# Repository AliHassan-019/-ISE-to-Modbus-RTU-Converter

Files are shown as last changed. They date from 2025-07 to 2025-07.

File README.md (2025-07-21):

<h1 align="center">ISE-to-Modbus-RTU-Converter</h1>

<p align="center">
  <b>Precision Analog Front-End & Industrial Modbus RTU Converter</b><br>
  <i>Robust, Isolated, and Noise-Immune Hardware for Scientific & Industrial Sensing</i>
</p>

---

<p align="center">
  
  
  
</p>

---

## 🚀 Overview

The **ISE-to-Modbus-RTU-Converter** is a state-of-the-art embedded hardware platform designed for high-precision analog signal acquisition and robust digital communication in industrial and scientific environments. It features a multi-stage, isolated power supply, a 24-bit high-resolution ADC, and a powerful microcontroller for seamless Modbus RTU communication. This converter is ideal for interfacing with pH (ISE) sensors, gas sensors, biomedical instrumentation, and other applications requiring accurate, low-level signal acquisition and reliable industrial communication.

---

## 🎯 Project Objectives

The primary goal is to deliver a robust, electrically isolated, and noise-immune analog front-end that ensures:
- **Accurate low-level signal acquisition**
- **Reliable, standards-compliant Modbus RTU communication**
- **Electrical safety and EMI immunity**
- **Easy integration with PLCs, SCADA, and industrial controllers**

---

## ⚙️ Features

- **Multi-stage Isolated Power Supply**: +12V input, isolated DC-DC, low-noise LDO for analog and digital domains
- **High-Resolution ADC**: 24-bit, differential input, programmable gain, internal/external reference
- **Industrial Microcontroller**: 32-bit, low-power, with SPI, I2C, UART/RS-485, GPIO
- **Modbus RTU Communication**: Hardware RS-485 transceiver, direction control, robust protocol stack
- **Peripheral Support**: I2C EEPROM, 1-Wire temperature sensor, test points, debug header
- **4-Layer PCB**: Optimized for EMI, thermal, and mechanical performance
- **Comprehensive Firmware**: Real-time data acquisition, Modbus stack, diagnostics

---

## 🏗️ System Architecture

```mermaid
graph TD;
    PWR[+12V Input] --> PROT[Protection: Diode & Fuse]
    PROT --> DCISO[Isolated DC-DC Converter]
    DCISO --> LDO[Low-Noise LDO Regulator]
    LDO --> VANA[+3.3V Analog Supply]
    VANA --> MCU[Microcontroller]
    VANA --> ADC[24-bit ADC]
    ADC -->|SPI| MCU
    MCU -->|UART/RS-485| RS485[RS-485 Transceiver]
    MCU -->|I2C| EEPROM[EEPROM]
    MCU -->|1-Wire| TEMP[DS18B20 Temp Sensor]
    MCU --> GPIO[GPIO/Debug]
```

---

## 🖥️ Schematic

<p align="center">
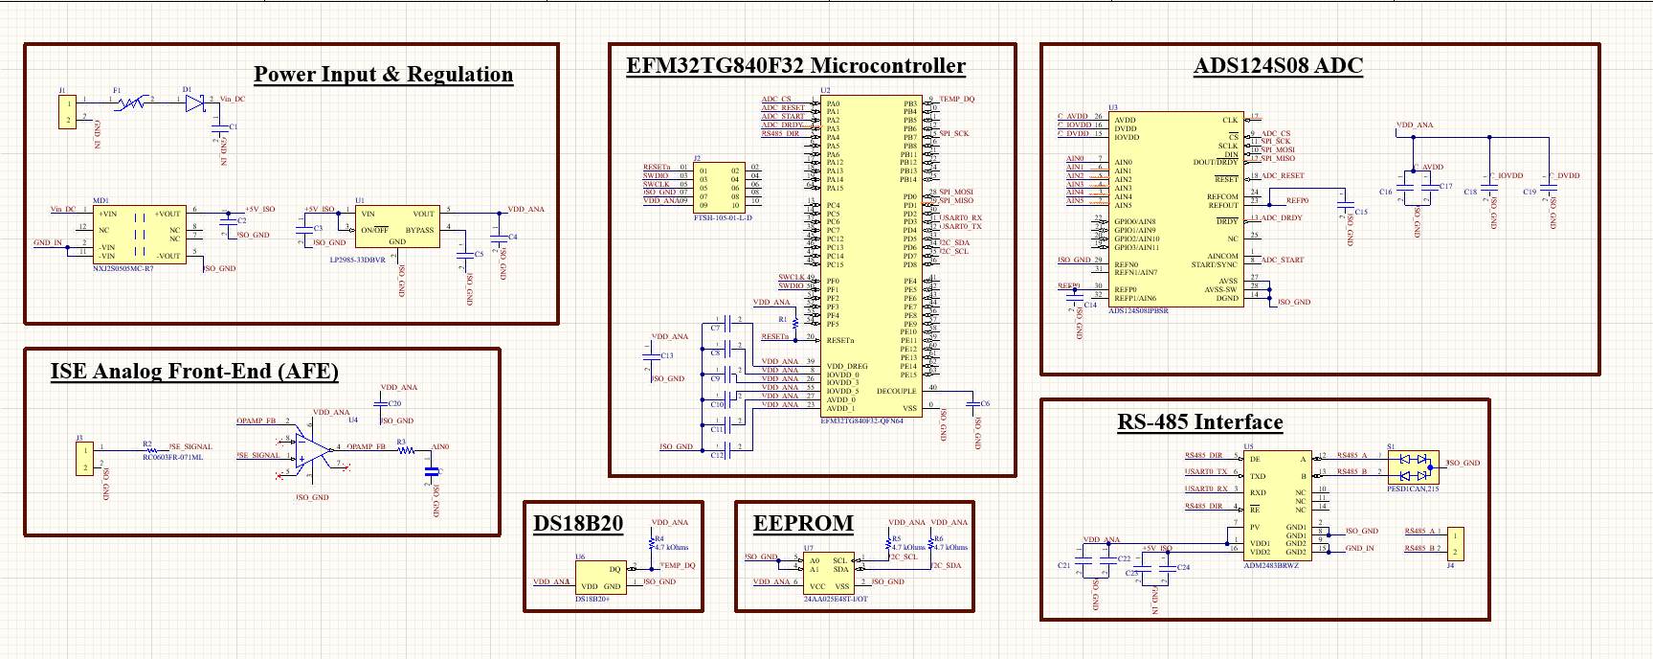
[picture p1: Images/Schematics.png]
Schematic
  
</p>

---

## 📐 Hardware Design

### Power Supply
The power supply accepts a +12V input, protected by a diode and fuse, and feeds an isolated DC-DC converter. The +5V_ISO output is regulated to a low-noise +3.3V analog supply via an LDO. This architecture ensures galvanic isolation and minimal noise for sensitive analog measurements.

### Microcontroller
A low-power, 32-bit MCU (e.g., EFM32TG840F32) manages all digital interfaces, including SPI (for ADC), I2C (for EEPROM), UART/RS-485 (for Modbus), and GPIOs. The MCU is powered from the clean analog supply, maintaining a unified ground reference.

### ADC
The ADS124S08 (or similar) 24-bit ADC interfaces with differential analog sensors. It supports programmable gain, internal/external reference, and advanced filtering for high-accuracy measurements.

### Communication
An RS-485 transceiver with direction control enables robust Modbus RTU communication. I2C EEPROM provides non-volatile storage, and a DS18B20 1-Wire sensor monitors board temperature.

### Layout & Decoupling
All blocks are decoupled with high-frequency capacitors, with careful separation of analog and digital ground planes. EMI filters and ferrite beads are used to suppress noise and ensure signal integrity.

## 🧩 PCB Design & Stack-Up

This project uses a 4-layer PCB for optimal signal integrity and EMI performance:

- **Top Layer:** Components, high-speed and analog routing
- **Inner Layer 1 (GND):** Solid ground plane for shielding and return paths
- **Inner Layer 2 (Power):** Clean analog/digital power rails (+3.3V, +5V_ISO)
- **Bottom Layer:** Passives, low-priority signals, mechanical support

**Board Size:** 200mm × 16mm (optimized for DIN-rail or slim enclosures)

---

## 🖼️ PCB Visuals

### Top 3D View
<p align="center">
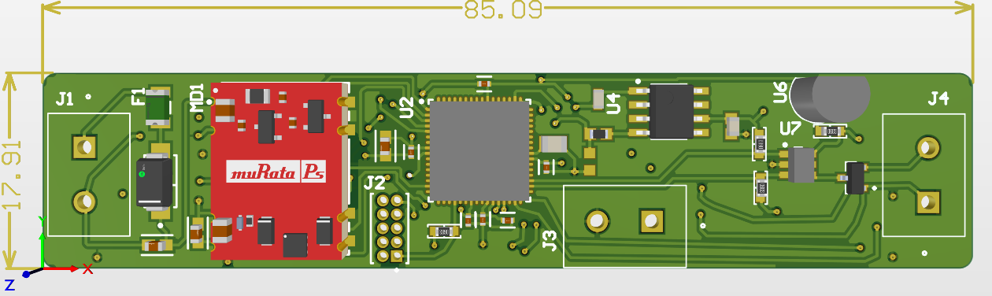
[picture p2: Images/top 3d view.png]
Top 3D View
  
</p>
This view shows the populated top side, including the MCU, ADC, protection, and filtering components. Placement is optimized for signal flow and manufacturability.

### Bottom 3D View
<p align="center">
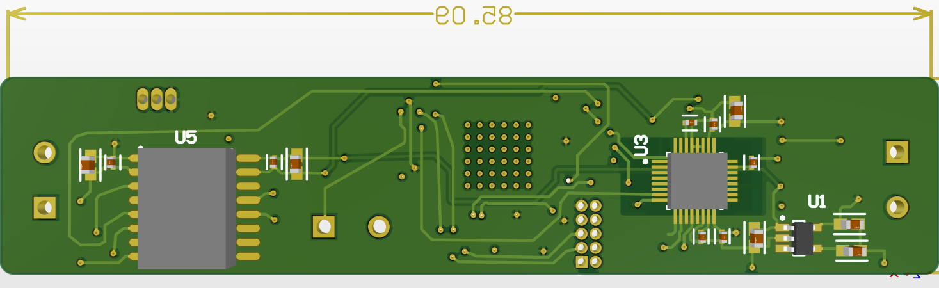
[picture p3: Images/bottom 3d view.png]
Bottom 3D View
  
</p>
The bottom side contains SMD passives, vias, and traces, kept clean for soldering and signal routing.

### Top Layer
<p align="center">
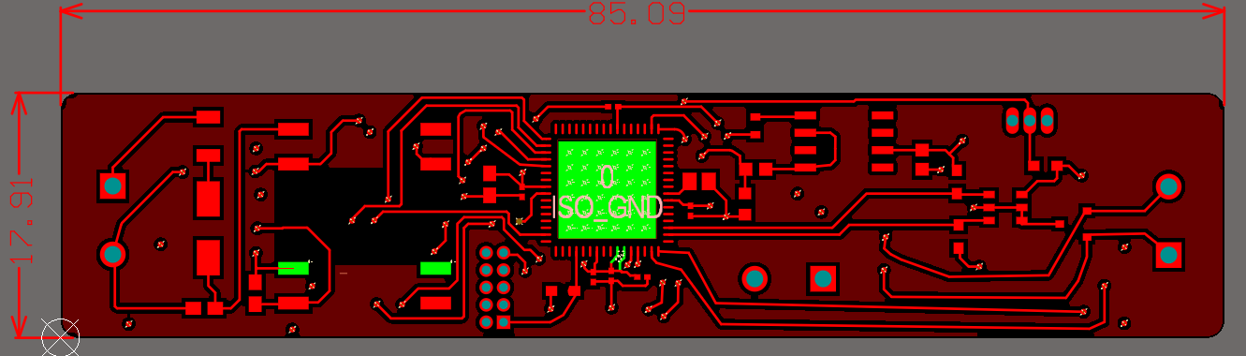
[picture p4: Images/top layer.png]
Top Layer
  
</p>
Main analog and digital signal routing, with careful clearance between domains.

### Inner Ground Layer
<p align="center">
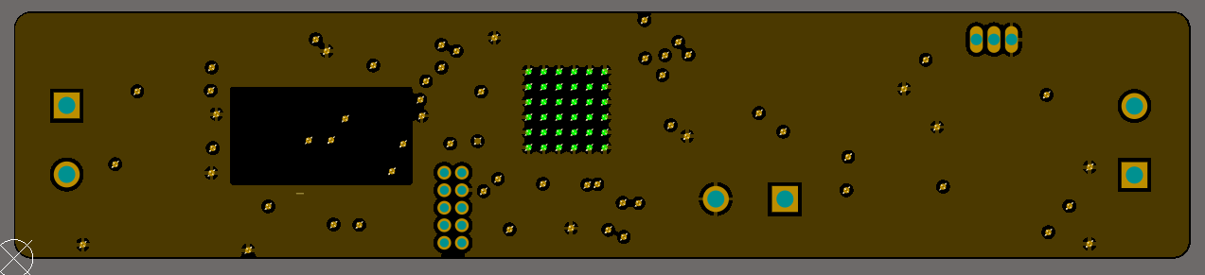
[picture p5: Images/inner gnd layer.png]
Inner GND Layer
  
</p>
Solid copper pour for low-impedance return and shielding.

### Inner Power Layer
<p align="center">
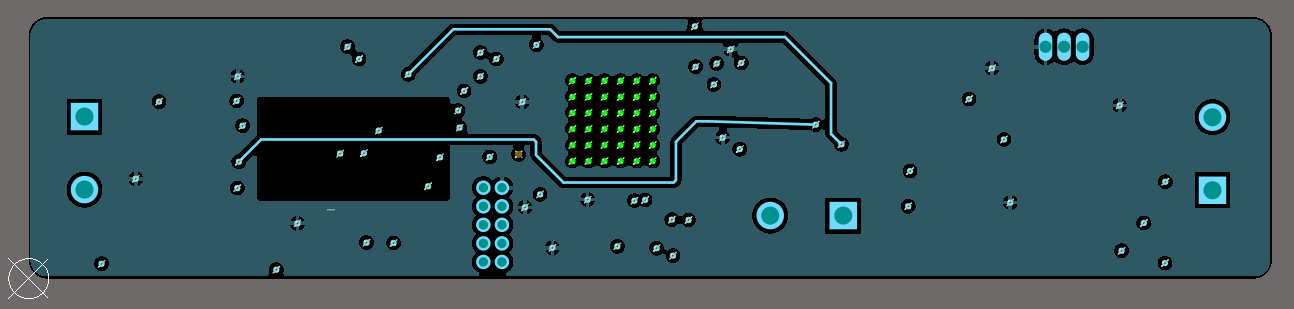
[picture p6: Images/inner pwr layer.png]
Inner Power Layer
  
</p>
Dedicated to analog and digital power rails, minimizing voltage drop and noise.

### Bottom Layer
<p align="center">
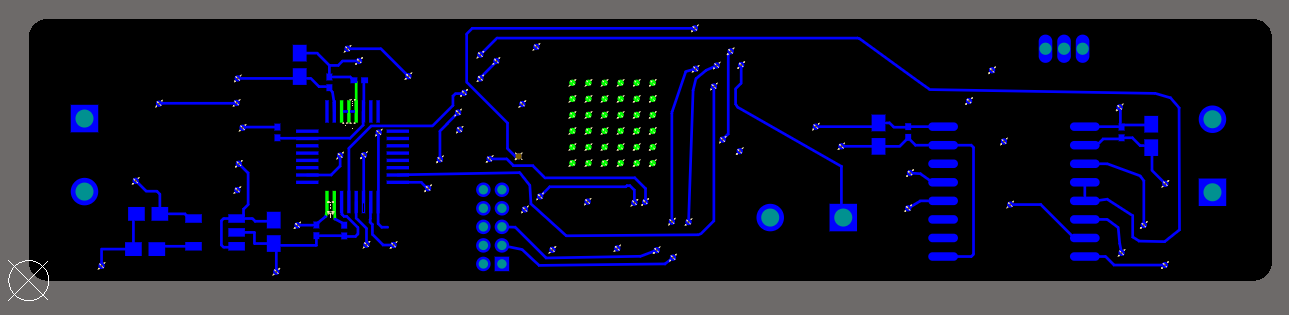
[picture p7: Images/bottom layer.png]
Bottom Layer
  
</p>
Routes non-critical signals, test points, debug, and low-priority GPIOs.

---

## 🧠 Firmware Overview

The firmware, developed in MCUXpresso IDE (or STM32CubeIDE), supports:
- SPI ADC configuration and data acquisition
- Real-time data processing and filtering
- Modbus RTU stack for RS-485 communication
- Diagnostics, error handling, and test point monitoring
- Flexible configuration for different sensor types and protocols

---

## 🛠️ Getting Started

1. **Power Up:** Connect a +12V supply to the input terminal.
2. **Programming:** Use the SWD header to flash the MCU with the provided firmware.
3. **Communication:** Connect RS-485 A/B lines to a Modbus master or PC (via USB-RS485 converter).
4. **Operation:** Use a terminal or GUI to send Modbus requests and read sensor data.
5. **Debugging:** Probe test points for ADC inputs and debug signals as needed.

---

## 📚 Documentation & Resources

- [Datasheet: ADS124S08 ADC](https://www.ti.com/product/ADS124S08)
- [MCU Reference Manual](https://www.silabs.com/documents/public/reference-manuals/efm32tg840f32.pdf)
- [Modbus RTU Protocol](https://modbus.org/docs/Modbus_over_serial_line_V1_02.pdf)
- [MCUXpresso IDE](https://www.nxp.com/design/software/development-software/mcuxpresso-software-and-tools/mcuxpresso-integrated-development-environment-ide:MCUXpresso-IDE)

---

## 📜 License

This project is licensed under the MIT License. You are free to use, modify, and distribute this design for commercial and non-commercial purposes, with proper attribution.

---

## 📬 Contact & Contributions

Contributions are welcome! Please fork the repository, submit issues, or open pull requests to improve the design. For questions, suggestions, or collaboration, contact the author via GitHub or email.

<p align="center">
  
  
</p>

---

<p align="center">
  <i>© 2025 ISE-to-Modbus-RTU-Converter. All rights reserved.</i>
</p>

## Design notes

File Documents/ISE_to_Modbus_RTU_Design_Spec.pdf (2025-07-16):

# ISE to Modbus RTU Converter – Design Specification

### Project Summary

Design a 4-layer PCB that reads a high-impedance mV signal from an Ion-Selective Electrode (ISE), digitizes it using a high-resolution ADC, applies temperature compensation and calibration, and transmits the result via Modbus RTU over RS-485.

### Confirmed Components

Function | Part
MCU | EFM32TG840F32 (QFN64)
ADC | ADS124S08 (24-bit, SPI)
Op-Amp | LMP7721 (ultra-low bias current)
RS-485 Transceiver | ADM2483 (isolated)
EEPROM | 24AA025E48 (I²C)
Temperature Sensor | DS18B20 (1-Wire digital)
PCB Stackup | 4-layer

### Signal Conditioning Path

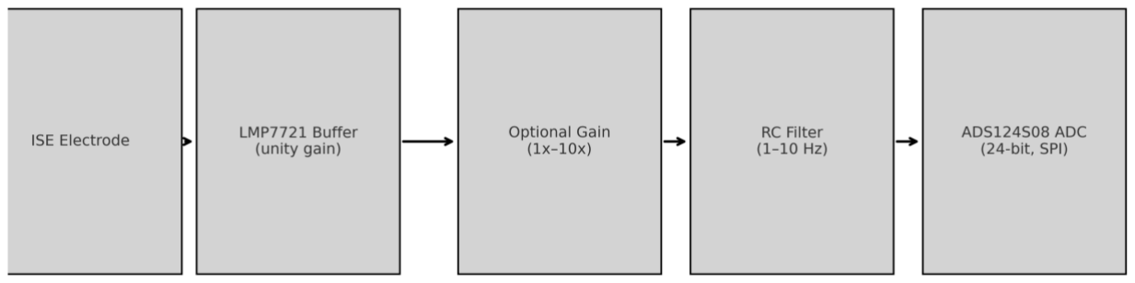
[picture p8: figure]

### Functional Blocks

- Signal Conditioning: LMP7721 buffer, optional gain stage (1x–10x), low-pass RC filter (~1– 10 Hz).
- ADC: ADS124S08 24-bit SPI, differential input.

- MCU: EFM32TG840F32 with SPI, UART, I²C.
- Temp Sensor: DS18B20 for compensation.
- RS-485: ADM2483, isolated, with TVS and 120Ω termination.
- EEPROM: 24AA025E48 to store calibration data and Modbus address.
- Power: 12V input, isolated DC-DC to 5V, LDO for analog.

### Connectors

- Terminal blocks for ISE input, RS-485, 12V power.
- 1-Wire header for DS18B20.
- SWD header for MCU programming.

### PCB Layout Notes

- 4-layer: Top (Signal), L2 (Ground), L3 (Power), Bottom (Signal).
- Isolated RS-485 domain.
- Ground separation: analog vs. digital.
- Low-noise routing from op-amp to ADC.

### Deliverables Required

- Altium schematic and 4-layer PCB layout.
- BOM with complete part numbers.
- Gerber and drill files.
- Firmware (EFM32): ADC, EEPROM, DS18B20, Modbus RTU.
- Documentation: pinout, register map, calibration, wiring.

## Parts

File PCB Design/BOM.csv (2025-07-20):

Comment | Description | Designator | Footprint | LibRef | Quantity
CL10B104KO8NNNC | 0.1ÂµF Â±10% 16V Ceramic Capacitor X7R 0603 _1608 Metric_ | C | CAPC1608X90N | CL10B104KO8NNNC | 1
GRM188R60J106ME47D | Chip Multilayer Ceramic Capacitors for General Purpose, 0603, 10uF, X5R, 15%, 20%, 6.3V | C1, C2, C3, C4, C5, C13, C17, C22, C24 | FP-GRM188-0_1-e0_2_0_55-IPC_A | CMP-2006-02792-2 | 9
C0805C105K4PACTU |  | C6 | CAPC2013X145X50LL20T25 | CMP-1036-04746-2 | 1
C1005X7R1H104K050BB | Multilayer Ceramic Capacitors 100nF ±10% 50V X7R SMD 0402 | C7, C8, C9, C10, C11, C12, C14, C15, C16, C18, C19, C21, C23 | FP-C1005-050-0_05-IPC_C | CMP-2000-05393-2 | 13
GRM188R71C104KA01D | CAP, Ceramic, 0.1 uF, 10%, 16 V, 0603, RoHS, Tape and Reel | C20 | MURA-0603_H_0.9_M | CMP-2000-05253-1 | 1
SS14 | DIODE SCHOTTKY 40V 1A SMA | D1 | FP-403AE-MFG | CMP-2000-04943-2 | 1
1206L050YR | PTC RESET FUSE 6V 500MA 1206 | F1 | FP-1206L050YR-MFG | CMP-08606-000073-1 | 1
OSTTC020162 | 2 Position Wire to Board Terminal Block Horizontal with Board 0.197 _5.00mm_ Through Hole | J1, J3, J4 | OST_OSTTC020162 | OSTTC020162 | 3
FTSH-105-01-L-D |  | J2 | SAMTEC_FTSH-105-01-L-D | FTSH-105-01-L-D | 1
NXJ2S0505MC-R7 | DC DC CONVERTER 5V 2W | MD1 | FP-NXJ2SM-MFG | CMP-20596-000009-1 | 1
10 kOhms | RES SMD 10K OHM 1% 1/10W 0603 | R1 | YAGEO RES 0603_1608 | AA0603FR-0710KL | 1
RC0603FR-071ML | Chip Resistor, 1 MOhm, +/- 1%, 100 mW, -55 to 155 degC, 0603 (1608 Metric), RoHS, Tape and Reel | R2 | RESC1608X55X25LL10T15 | CMP-1659-00056-1 | 1
RC0603FR-07100RL | 100 Ohms Â±1% 0.1W, 1/10W Chip Resistor 0603 (1608 Metric) Moisture Resistant Thick Film | R3 | RESC1607X60N | RC0603FR-07100RL | 1
4.7 kOhms | RES SMD 4.7K OHM 1% 1/10W 0603 | R4, R5, R6 | YAGEO RES 0603_1608 | AC0603FR-074K7L | 3
PESD1CAN,215 | 70V Clamp 3A (8/20Âµs) Ipp Tvs Diode Surface Mount TO-236AB | S1 | DIO_PESD1CAN,215 | PESD1CAN,215 | 1
LP2985-33DBVR | Single Output Low Noise LDO, 150 mA, Fixed 3.3 V Output, 1.5% Tolerance, 2.2 to 16 V Input, Low IQ, 5-Pin SOT-23 (DBV), -40 to 125 degC, Green (RoHS & no Sb/Br), Tape and Reel | U1 | DBV0005A_M | CMP-0758-00080-2 | 1
EFM32TG840F32-QFN64 | EFM32 Tiny Gecko, M3 ARM Cortex CPU, 32 KB Flash, 4 KB RAM, 1.85 - 3.8 V Supply, 32 MHz Max Speed, -40 to 85 degC, 64-Pin QFN, RoHS Compliant | U2 | ENMR-QFN64_N | CMP-0270-00147-1 | 1
ADS124S08IPBSR | IC ADC 24BIT SIGMA-DELTA 32LQFP | U3 | FP-PBS0032A-MFG | CMP-04860-000020-1 | 1
LMP7721MA/NOPB | 3 Femtoampere Input Bias Current Precision Amplifier, 8-pin Narrow SOIC, Pb-Free | U4 | D0008A_M | CMP-0055-00395-3 | 1
ADM2483BRWZ | Half-Duplex, iCoupler(R) Isolated RS-485 Transceiver , 500 Kbps , -40 to 85 degC, 16-Pin SOIC (RW-16), RoHS, Tube | U5 | ADI-ADM2483BRWZ-16_M | CMP-2000-05041-1 | 1
DS18B20+ | Programmable Resolution Digital Thermometer, 1-Wire Interface, ±0.5°C Accuracy, 3-Pin TO92, -55°C to +125°C, Pb-Free | U6 | Q3+1 | CMP-0253-00003-1 | 1
24AA025E48T-I/OT | 2K bits I2C™ Serial EEPROM with EUI-48™ Node Identity, 1.7 to 5.5 V, 400 kHz, -40 to 85 degC, 6-pin SOT-23 (OT6), Tape and Reel | U7 | MCHP-SOT-23-OT6_L | CMP-0159-01033-1 | 1

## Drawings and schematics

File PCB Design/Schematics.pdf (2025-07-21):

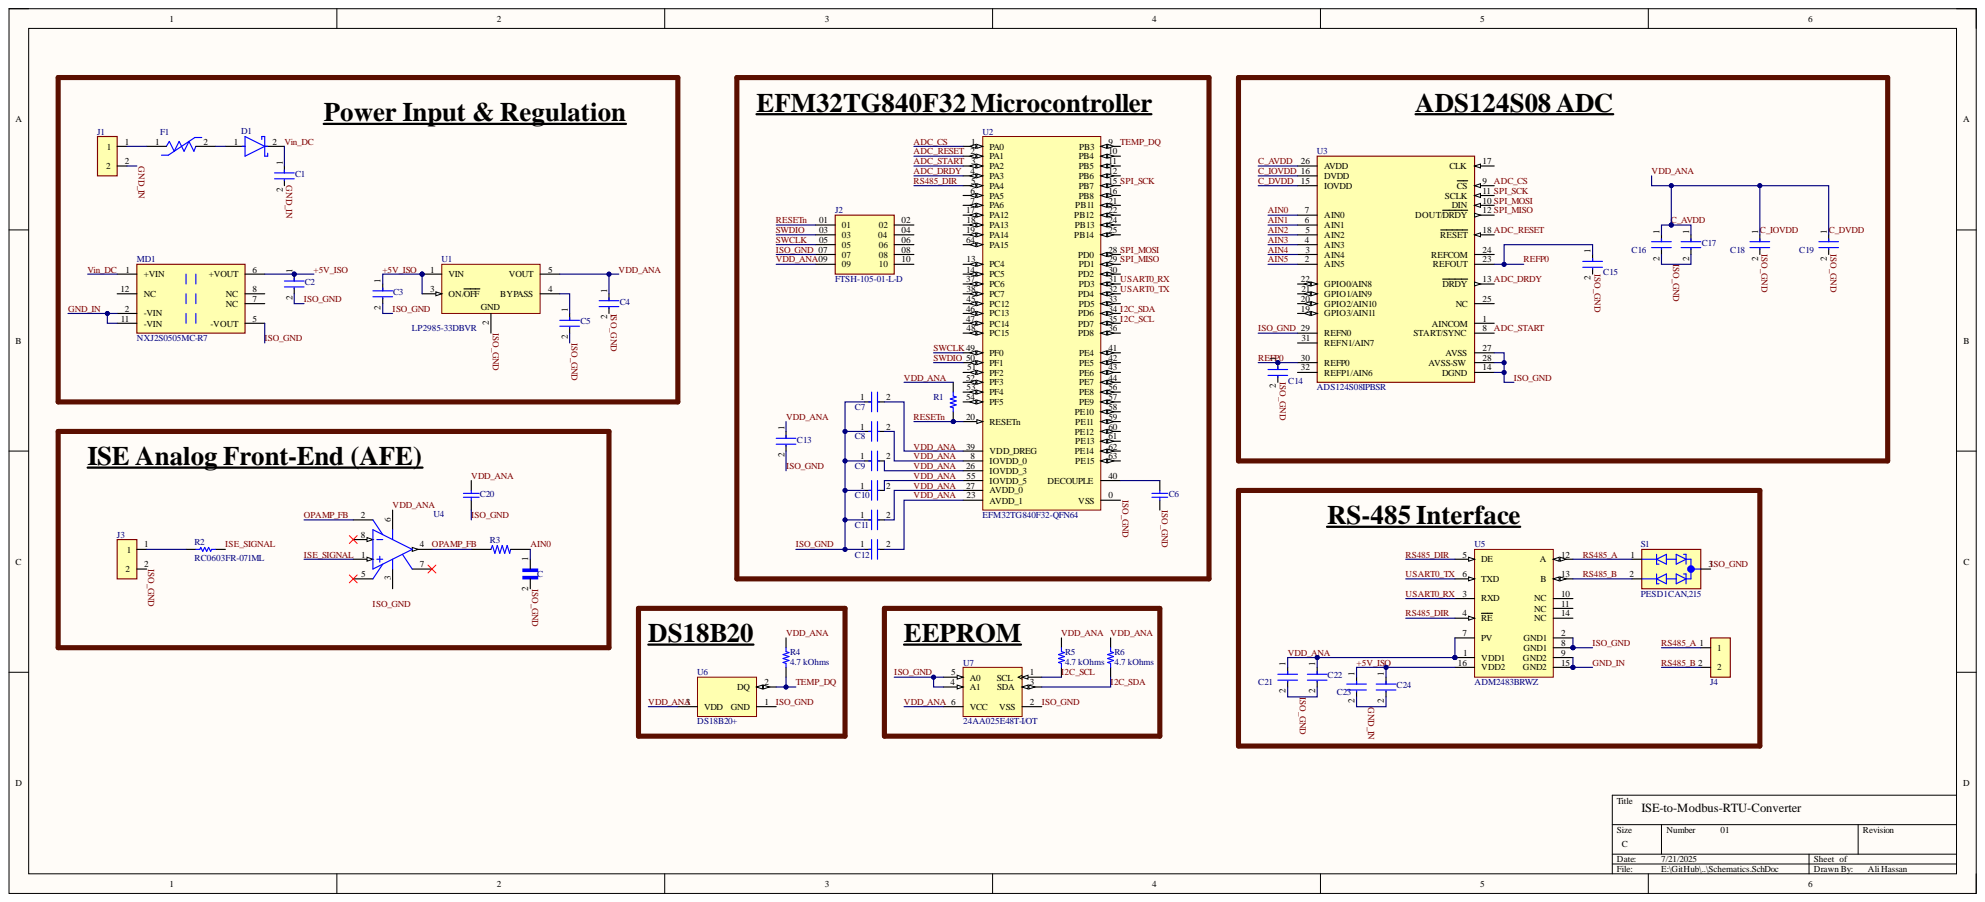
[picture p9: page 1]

Size | Number 01 | Revi s i on

e : 7/21/202 5 | Sheet of
Fi le: E : \ G i t Hub\..\Schemat ics.Sc hD oc | D rawn B y : A l i Has san

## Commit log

2025-07-16 Power Input & Regulation
    [PCB Design.PrjPcb, Schematics.SchDoc]
2025-07-16 step2 in process
    [Schematics.SchDoc]
2025-07-18 pcb (cont ...)
    [PCB Design.PrjPcb, PCB.PcbDoc, Schematics.SchDoc]
2025-07-19 1st pcb design
    [PCB.PcbDoc]
2025-07-19 2nd PCB Design
    [PCB.PcbDoc]
2025-07-20 final pcb design
    [PCB.PcbDoc, Schematics.SchDoc]
2025-07-21 Final Design
    [PCB Design.PrjPcb, PCB.PcbDoc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]

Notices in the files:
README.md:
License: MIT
